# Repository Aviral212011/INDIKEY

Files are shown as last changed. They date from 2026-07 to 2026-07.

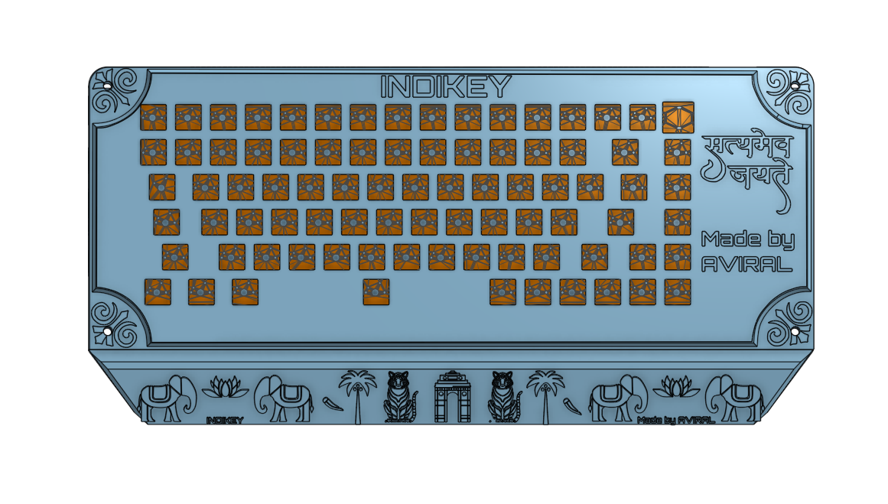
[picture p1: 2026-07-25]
images/Screenshot 2026-07-25 134613.png

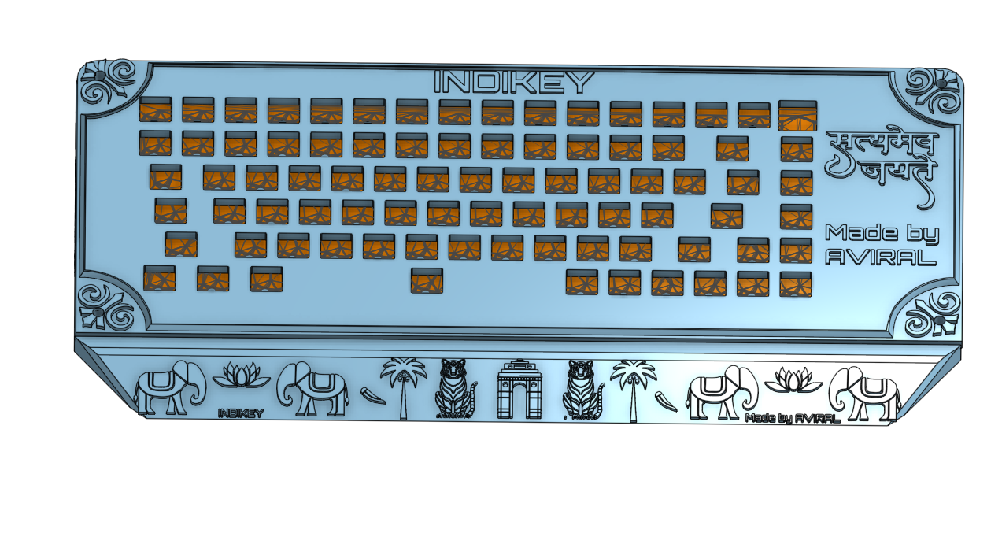
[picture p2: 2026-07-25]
images/Screenshot 2026-07-25 135329.png

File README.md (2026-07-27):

## INDIKEY- 
---

A custom made 65 % keyboard made with classical indian asthetics . it is made on royal indian theme . the microcontroller used is raspberry pi pico and pcb is designed in kicad and the case is designed in onshape  . 
--- 
# features - 
* rapberry pi pico
* custom case
* custom pcb
* made on royal indian design
* rotary encoder
* 65 % keyboard size
  
---
  
## preview 






* case

* schematics


* pcb



*  pcb 3d view
  
---
  
# link to onshape (case) -
https://cad.onshape.com/documents/4f19f8146dbdff3fb7b6736f/w/b2633a3228cab1fe44c80062/e/a95599da6178e9e3f19ca7d5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

---
##BOM
# 📦 Bill of Materials (BOM) — INDIKEY

| Name | Qty | Final Price - INR (USD) | Link |
| :--- | :---: | :---: | :---: |
| MX Switches | 83 | *16299[$170]* | [here](https://amzn.in/d/06A2sHGW) |
| Keycaps Set (Standard Layout) | 1 | *2000[$21]* | [here](https://amzn.in/d/00yRvEXN) |
| Stabilizers (Screw-In / Plate-Mounted) | 1 | *4000[$40]* | [here](https://amzn.in/d/065cqTSa) |
| Diode 1N4148 Through-Hole | 84 | *200[$2]* | [here](https://amzn.in/d/05sHaeOd) |
| EC11 Rotary Encoder | 1 | *200[$2]* | [here](https://amzn.in/d/0c7ub54C) |
| Raspberry Pi Pico | 1 | *1000[$10]* | [here](https://amzn.in/d/02kN8avH) |
| PCB (Custom pcb - INDIKEY) | 5 | *6047[$63.09]* | — |
| 3D Printed Case (Top & Base) | 1 | *--* | Print legion |
| M3 x 20mm Bolt / Screws | 4 | *179[$1.87]* | [here](https://amzn.in/d/04auqHwD) |
| M3 Heatset Inserts / Nuts | 4 | *100[$1]* | [here](https://amzn.in/d/0b8RiXdv) |

---

### Total Pricing

The total price comes out to be **29,789 INR ($310.79)**.

> *Note: The pricing might slightly vary due to flash sales and currency exchange rates.*

---

* A special thanks to Anay jain who helped me a lot in this .
  
---

Designed and developed by **Aviral Sen**

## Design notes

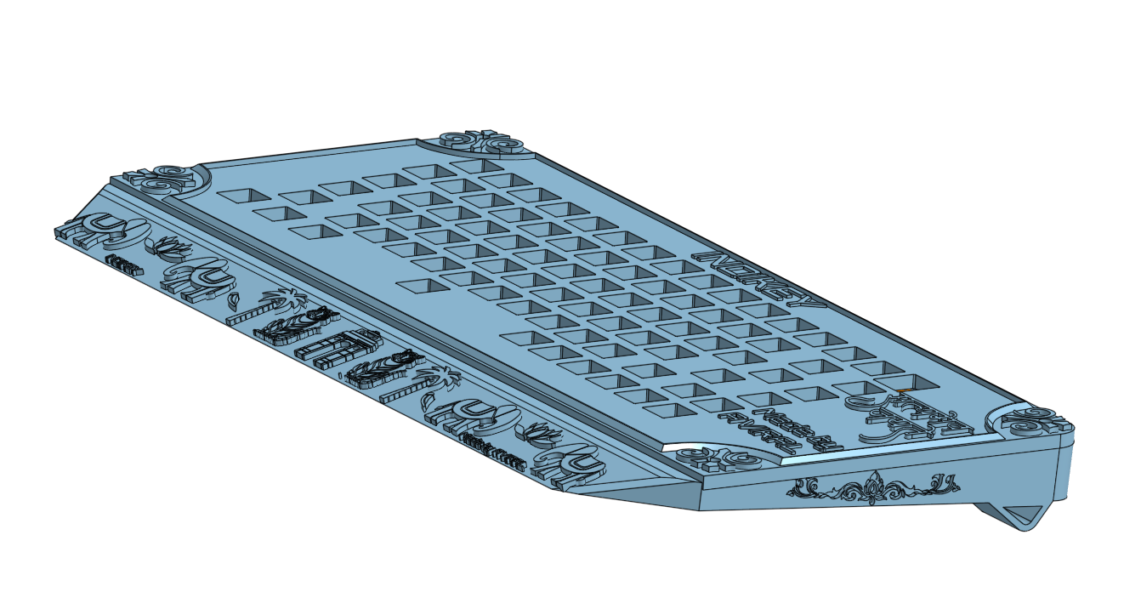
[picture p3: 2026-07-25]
images/Screenshot 2026-07-25 134643.png

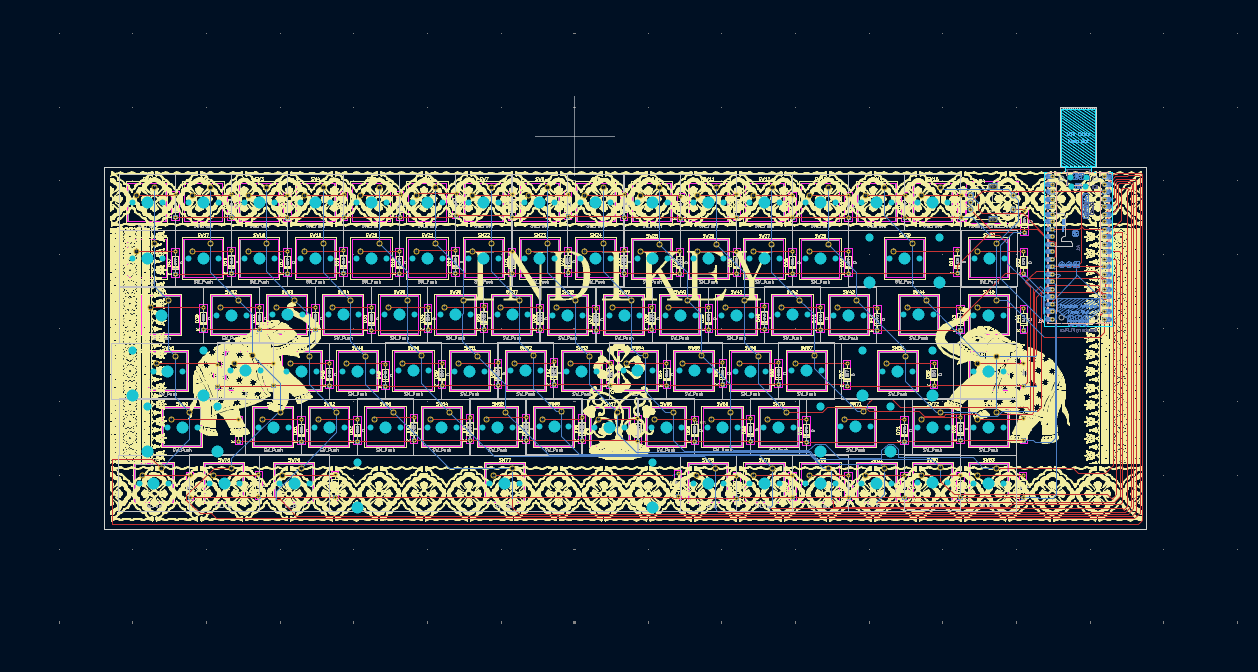
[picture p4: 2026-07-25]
images/Screenshot 2026-07-25 135557.png

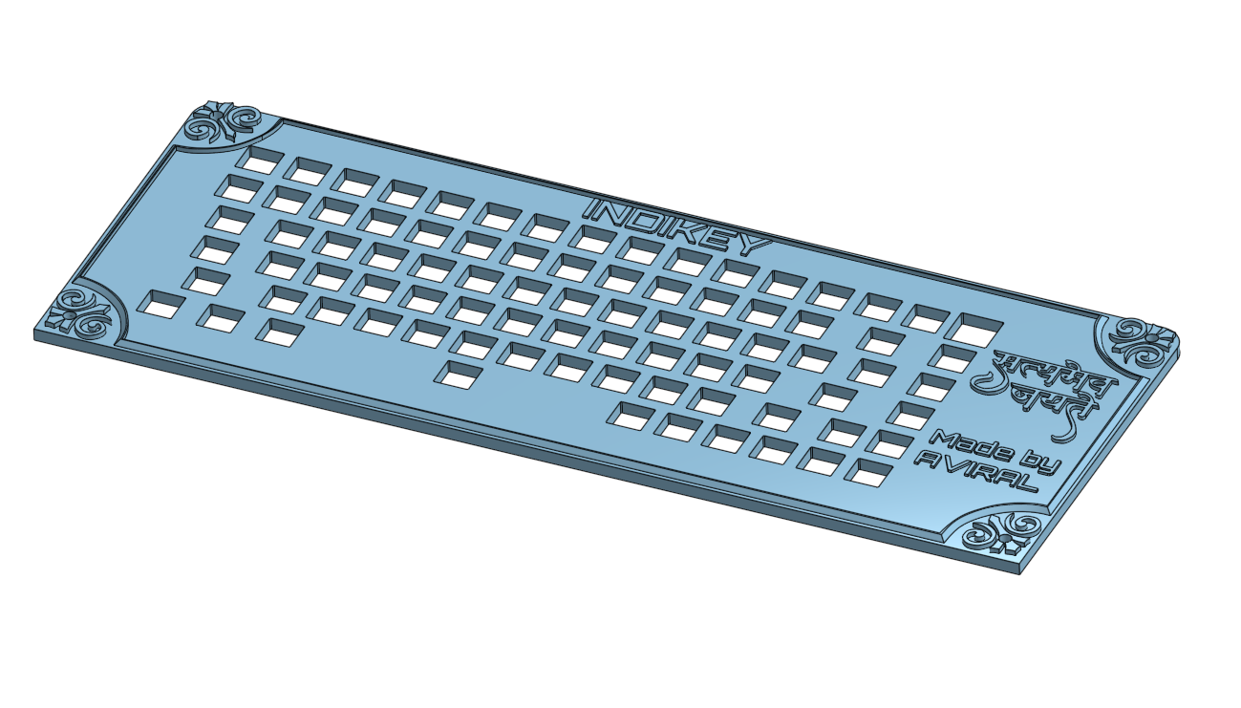
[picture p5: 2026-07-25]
images/Screenshot 2026-07-25 140106.png

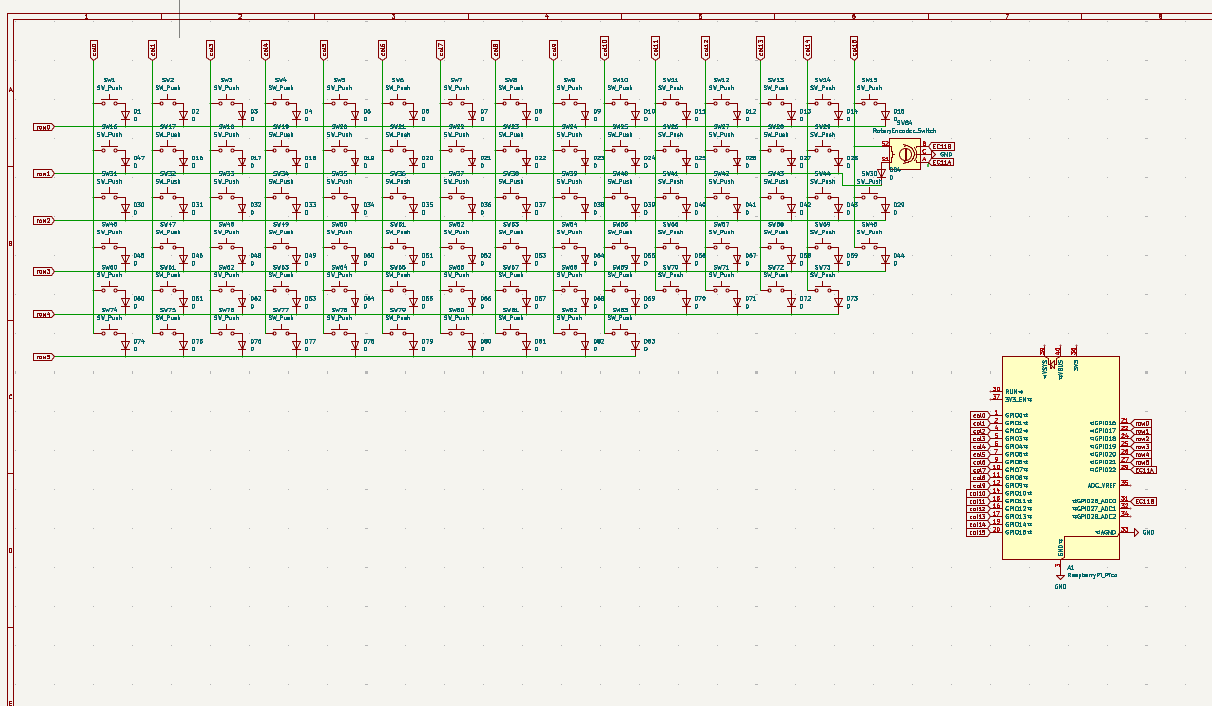
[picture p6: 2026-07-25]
images/Screenshot 2026-07-25 135510.png

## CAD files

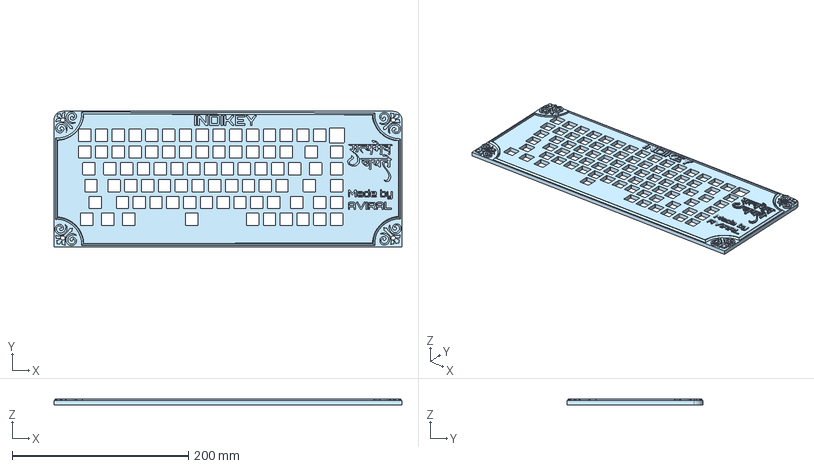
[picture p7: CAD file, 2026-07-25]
CASE/top (1).step
394.8 x 153.8 x 7.00 mm

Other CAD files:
CASE/top.stl

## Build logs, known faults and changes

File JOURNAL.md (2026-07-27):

## journal 1 
hey ! this is my second keyboard because i made my first keyboard few days ago but its pcb file got currupted and i was not able to complete it so i made this one . this is a 65 percent fully custom keyboard made on classical indian theme .
today i started with the schematics . at first i imported all the switches and then i imported our microcontroller raspberry pi pico . i wired all the switches together and i made the matix so that i can connect the all the components together very easily .
then i connect all teh components to the raspberry pi pico and now i am done with my schematics . 
* lapse- https://lapse.hackclub.com/timelapse/004TWzJI7v97
* time taken - 1 hour 7 min 
## journal 2 
after the completion the schematics i have to assign the footprints so that i can move towards the pcb designing . i used 1n4148 for diodes and sw_switch cherry mx for switches . and i will move towards the pcb editing . 
* lapse - https://lapse.hackclub.com/timelapse/JN0-KiQpeB3l
* time taken - 16 min 
## journal 3 
i assigned the foot prints and then i move towards the pcb editing . i imported all the components in the sheet and then i imported silkscreen of my layout which help me to put all the switches according to my layout . then i take each and every switch and placed it at their place according to my layout. thanks to the layout silkscreen which help me a lot but after this also this process takes a lot of time because i was now able to put the switches at once but i finally made that . i used 84 switches and it i was not easy to put each and every key accoring to the design . it takes time but it is worth .
* time taken - 1 hour 20 min 
* lapse - https://lapse.hackclub.com/timelapse/fm9-5I-VqnKJ
## journal 4 
i started placing the diodes in the similar way as i placed the switches and this is difficult because i have to place the diodes to the switch i connected to the same diode in the schematic . but i do it and it my whole time then i made some changes in the footprints like for the switches like spacebar and swift i need different footprint so i did that but i was not perfect so i have to do that again and again and finally i made that done . and then i placed our raspberry pi pico to the position where i need it and then i just created a 3d for the pcb to see that how everything is looking and i found that it is looking good right now . 
* time taken - 28 min + 54 min = 78 min 
* lapse - https://lapse.hackclub.com/timelapse/J8t0wv6vejEI and
https://lapse.hackclub.com/timelapse/63lTx4jkyGSc
## journal 5 
as after making everything clear i made some changes in the footprint as i want holes for some keys in the pcb to install the supports of keycaps which takes a little time then i started the wiring . i need clean and proper wiring so i started wiring each and every switch with their respective diodes with the top cu traces and then i wired each row and each coloum together whd then each row and coloum to the raspberry pi pico which is quite time consuming but it makes my pcb looks super clean and neat . 
* time taken - 41 min + 17 min = 58min
* lapse - https://lapse.hackclub.com/timelapse/BjP1V1qguGrv and https://lapse.hackclub.com/timelapse/-_NY-Y2sOJFK
## journal 6 
you know that my keyboard is based on classical and royal indian theme so its pcb must have some indian asthetics so i decided to add some . i download some borders from the internet then i added them on my pcb and then i add some royal elephant which make it look more classical and i also add a flower or i dont know the name of that thing in the middle with the front silk skin . i also added our horizons logo on its back and now our pcb is ready and now i have to movetowards the case . 
* time taken - 34 min
* lapse - https://lapse.hackclub.com/timelapse/P8h6EznExUti
## journal 7 
i created a new document and in it i created a new sketch on the top plane where i made a rectangle. then i taked the dimensions of my pcb and give dimension to the rectangle acccordding to it then i made another rectangle with my custom design and i leaved some space for the ports and all . i am also adding a hand rest in my design then i extrude upeverything and i want a slant type design so i made it accordingly . i used fillet for some place .then i made a stand at the back which make typing easy . then i adddd a lotus design on its side but it was not appriopriate there so i decided to add a more royal design . 
* time taken - 38 min + 35 min = 73 min 
* lapse - https://lapse.hackclub.com/timelapse/D5YR-poeDhwq and https://lapse.hackclub.com/timelapse/V9DzBr4ZxXKX
## journal 8
i imported the image of the design i want to make and then i start making its sketch on the side of my keyboard using the spline tool and then i completed the design in approx in less than a hour and then i used mirror tool to complete it . then i copied
the skecth and pasted it on the other side . then i adjusted it and extrude it and my design is completed . 
* time taken - 36 min and 33 min . total 69 min
* lapse- https://lapse.hackclub.com/timelapse/PMXXgbQXjdKW and https://lapse.hackclub.com/timelapse/qxWxJtiLlzEp
## journal 9 
i added a text of indikey on the back of the keyboard which ios lookin good . then i made four holes on the with the diameter of 3 mm and the base of my case's bottom is ready .
* time taken - 12 min and 15 min = total time 27 min .
* link to lapse - https://lapse.hackclub.com/timelapse/nJ9KcPhUHNZi and https://lapse.hackclub.com/timelapse/YrVMJhO6Mi-h
## journal 10 
i started making the top of my case . i made a new part studio in which i made a new skecth with the same dimension which i used in the bottom of the case .  then i downloaded the .json file of my keyboard layout and generate its plate using a tool . then i imported its dfx in the sketch and adjusted it according to the pcb . then i tried to make a design on its top like a diya or something i dont know . 
* time taken = 10 min + 19 min = total 29 min
* lapse - https://lapse.hackclub.com/timelapse/FjVhXX_hRfal and https://lapse.hackclub.com/timelapse/VApCLMvUe__T
## journal 11 
i made the diya design on both sides of all the keys but that was not workin at all . i spent over 1 hour on it but it is not looking good . so i deleted that design and started a new design on the same plane . which is really good . 
* time taken - 27min + 21 min = total time 48 min
* lapse - https://lapse.hackclub.com/timelapse/YA865uKP5-W8 and https://lapse.hackclub.com/timelapse/OSp3hRSMFXhj
## journal 12 
a the diya type design i tried to made was not at all pratical there so i decided to just add some text now . i added my credits on it and i decided to add a text of satymav jayate which is a slogan or a symbol of our great India 
then . i downloaded a good text of it and start making the skecth there with the help of spline tool . then i extrude it and it was looking good . 
* time taken - 1 hour
* lapse - https://lapse.hackclub.com/timelapse/29hahLGkl49G
## journal 13
then i think to add a royal type border because it is looking very simple . so i imported a the reference of that border in the partstudio and started making it with the spline tool on all the four corners and after that it was looking more royal and premium . in between i have to made some changes beacuse of some issue but i made it done . then i made many holes at the back of bottom for the proper ventilation ny drawing each hole . and then i made the hole for encoder a slighty bigger so that it can fit properly . 
* time taken- 34 min + 30 min
* lapse - https://lapse.hackclub.com/timelapse/33SQ0r82Xr5k and https://lapse.hackclub.com/timelapse/aXKsLh9Tj6xg
## journal 14 
now every thing is done but my keyboard handrest is looking so i decided to add some details in that that could match my theme so i found a template which shows the distinct culture of our india . it has india gate , tiger, elephant, lotus,cononut tree ,chili and many more stuff but i am adding these only . i divided my hand rest in two parts and after making the sketch on the left side i will make it with the mirror tool. at first i decided to make india gate first . i started making the skecth in the middle of my handrest . i draw the india gate with the lines and rectangles . tehn i drew the tiger whiich is a little complicated but cool . i made it with the help of spline tool and this is very time consuming . then i move towards the lotus and elephant . i darw the them also with the help of the refrence template . first i made the lotus and then i started with the elephant . elephant saddle was a little tricky to draw so i draw it more than twice time but at the end i completed it . then i made the coconut tree between the tiger and elephant with a boxy structure . then i copied everything to see that every thing is fitting on the other side or not and lucklyt everything fits perfectly . then i drew a red chilli on it  . then i adjusted the chillli and placed it in a perfect position . after that i added a text on it giving credits to me and than i copied every thing one by one to place that on the other side . i also added the text of indikey there . then i adjusted the positions of all the elements or stuff i added there to maintain the symmetry . and then i slect each part and extrude it with the suitble height and now finallyyyyy i am done with my first 65% keyboard made on Indian theme  **The INDIKEY** . 
* time taken - 27 min + 30 min + 39 min + 40 min + 23 min + 36 min + 1 hour 15 min = total time 270 min 
* lapse- https://lapse.hackclub.com/timelapse/4GKDcN1xvEBp --- https://lapse.hackclub.com/timelapse/TKLty3rsYz0I --- https://lapse.hackclub.com/timelapse/IVun4l5hRoFd --- https://lapse.hackclub.com/timelapse/J8fAKAM94XhY --- https://lapse.hackclub.com/timelapse/tVg7UEYosyLr--- https://lapse.hackclub.com/timelapse/LZepiMCrbBp_ --- https://lapse.hackclub.com/timelapse/PSlvIgVxmwoa .

  ---
  **the final design**


--- 

**Total time taken So Far = 18 hours**
